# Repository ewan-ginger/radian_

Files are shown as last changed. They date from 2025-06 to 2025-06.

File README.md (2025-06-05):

# RADIAN_: An Open-Source IMU-Based Wireless Sensor Network for Team Sports Analytics

## Project Abstract

Access to performance analytics in team sports is increasingly essential at elite levels but remains largely inaccessible
to amateur players due to high system costs and complex workflows. Here we present RADIAN, an open-source,
IMU-based wireless sensor network embedded into lacrosse sticks, with the aim of enabling high-fidelity player and
team analytics without external infrastructure or specialist expertise. Built from off-the-shelf components, the system
uses the ESP-NOW protocol to transmit real-time inertial data up to 120m under ideal field conditions. We show
that the system achieves an F1 score of 0.95 in classifying six core lacrosse actions using a trained XGBoost model.
This was enabled by a novel, automated labelling pipeline developed for the sports context, reducing the need for
manual annotation and allowing scalable training data collection. Furthermore, an exploratory LLM reasoning layer
improved an ensemble model’s F1 score from 0.726 to 0.763 in game conditions, demonstrating potential for nuanced
event interpretation. RADIAN demonstrates that accurate, real-time analytics can be delivered through accessible
hardware, offering a pathway to close the gap between elite and grassroots athletic performance.

## Repository Structure
Use code with caution.

├── CAD/

│   ├── Master Node.f3z

│   ├── Master Node.step

│   ├── Slave Node.f3z

│   └── Slave Node.step

├── Code/                    

│   ├── Classification/       

│   ├── Firmware/             

│   ├── GUI/                  

│   └── LLM/                  

├── Data/                     

│   ├── 2v2 Data/             

│   └── Training Data/       

├── Personal Reflection/      

│   └── personal_reflection.md

├── Project Management/       

│   ├── gantt_chart.png

│   └── project_management.md

├── STLs/                     

│   ├── Butt End.stl

│   ├── Master Node Body Bottom.stl

│   ├── Master Node Top.stl

│   ├── Slave Node Body Left.stl

│   └── Slave Node Body Right.stl

├── Survey Results/         

│   ├── RADIAN Coach Feedback Survey(1-2...).xlsx

│   └── RADIAN Player Feedback Survey(1-1...).xlsx

├── Videos/                   

├── .gitignore              

├── README.md

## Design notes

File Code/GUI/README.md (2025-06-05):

# Radian - Sports Analytics Dashboard

This is a sports analytics dashboard built with Next.js, TypeScript, Shadcn UI, and Supabase. The application allows for real-time tracking and visualization of player movement data collected from ESP32 devices via the Web Serial API.

## Features

- Connect to ESP32 devices using Web Serial API
- Record and visualize player movement data in real-time
- Store and analyze historical session data
- Manage player profiles and session information
- Dark mode support with customizable theme

## Getting Started

First, run the development server:

```bash
npm run dev
# or
yarn dev
# or
pnpm dev
# or
bun dev
```

Open [http://localhost:3000](http://localhost:3000) with your browser to see the result.

## Project Structure

- `app/`: Next.js App Router pages and layouts
- `components/`: Reusable UI components
- `lib/`: Utility functions and services
  - `supabase/`: Supabase client and database operations
  - `serial/`: Web Serial API utilities
  - `data/`: Data processing and transformation
- `hooks/`: Custom React hooks
- `types/`: TypeScript type definitions
- `providers/`: Context providers for state management

## Technologies Used

- [Next.js](https://nextjs.org/) - React framework
- [TypeScript](https://www.typescriptlang.org/) - Type safety
- [Shadcn UI](https://ui.shadcn.com/) - Component library
- [Tailwind CSS](https://tailwindcss.com/) - Styling
- [Supabase](https://supabase.com/) - Backend and database
- [Web Serial API](https://developer.mozilla.org/en-US/docs/Web/API/Serial) - Device communication

## Development

This project follows a structured implementation plan with clearly defined steps. See the `project-steps.md` file for details on the implementation roadmap.

This project uses [`next/font`](https://nextjs.org/docs/app/building-your-application/optimizing/fonts) to automatically optimize and load [Geist](https://vercel.com/font), a new font family for Vercel.

## Learn More

To learn more about Next.js, take a look at the following resources:

- [Next.js Documentation](https://nextjs.org/docs) - learn about Next.js features and API.
- [Learn Next.js](https://nextjs.org/learn) - an interactive Next.js tutorial.

You can check out [the Next.js GitHub repository](https://github.com/vercel/next.js) - your feedback and contributions are welcome!

## Deploy on Vercel

The easiest way to deploy your Next.js app is to use the [Vercel Platform](https://vercel.com/new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) from the creators of Next.js.

Check out our [Next.js deployment documentation](https://nextjs.org/docs/app/building-your-application/deploying) for more details.

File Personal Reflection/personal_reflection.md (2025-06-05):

# Project Reflection

This project provided a rare opportunity to bring together a broad range of design engineering skills developed throughout my time at Imperial. From early-stage prototyping to machine learning and stakeholder engagement, the work demanded a multidisciplinary approach—and it was deeply rewarding to apply so many aspects of what I’ve learned in a single, cohesive output.

Revisiting the initial benchmarks—keeping the build under £50, under 55 grams, and achieving at least 92% F1 score on action recognition—offered a clear lens for evaluation. Reaching a build cost of around £30 and a final device weight of 25 grams felt like a genuine high point, especially when the 3D-printed housing slotted cleanly onto a standard lacrosse shaft, exactly as intended. That sense of translating a digital concept into a precise physical outcome echoed many of the rapid prototyping and CAD exercises I’d practised during my degree.

On the analytics side, achieving approximately 95% accuracy for isolated action detection was a strong validation of the machine-learning pipeline I developed. It drew directly on the technical foundations laid during data science and computing modules. However, the process also exposed areas for improvement—specifically, the automated labelling workflow introduced more “null” windows than expected, often due to actions occurring in close succession. In hindsight, I recognise that I moved too quickly from labelling to model training, and would now spend more time fine-tuning the segmentation thresholds. Balancing speed of development with rigour in validation is a key lesson I’ll take forward.

The technical range of the project meant constantly shifting gears. CAD and form development felt second nature; designing the butt-cap in Fusion 360 and iterating it rapidly was a familiar process. In contrast, firmware and embedded systems required learning on the fly. I had limited experience working at that level of hardware abstraction, so optimising the ESP32’s sleep modes and setting up hardware interrupts was a steep learning curve. Debugging power issues made me realise that app-level prototyping skills don’t always translate smoothly to embedded development—but the challenge was incredibly valuable.

On the machine learning front, building and training a Convolutional Neural Network pushed me to explore new tools like TensorFlow and experiment with techniques such as stratified cross-validation. Watching the model improve was satisfying, but I noticed a tendency to over-optimise—pursuing marginal gains without always asking whether the added complexity was meaningful. Going forward, I’ll set more disciplined performance thresholds and aim to simplify rather than overfit.

Beyond the technical work, the project gave me the chance to practise user research and product thinking in context. My training in user-centred design was particularly useful when gathering feedback from lacrosse players—turning those insights into tangible design improvements for the housing was a great example of design iteration grounded in real user needs. At the same time, trying to optimise the power budget exposed clear limitations in my understanding of electronics. Interpreting datasheets and modelling power draw didn’t come easily, and it’s an area I now plan to actively improve. I’m hoping to take on a smaller personal project—perhaps a basic wearable step counter—that will give me a focused way to learn about PCB design, battery selection, and current estimation without the overhead of a large codebase.

In many ways, this project felt like a culmination of my time at Imperial—it challenged me to integrate design, engineering, data, and human factors in a way that mirrored real-world product development. The variety of skills required made it especially enjoyable. To keep improving, I’ve already planned to refactor sections of the codebase into a more maintainable pipeline and conduct extended field tests—such as multi-stick scrimmages—to stress-test the system under more chaotic conditions. I’m also aiming to improve how I present results to non-technical stakeholders, using clearer visualisations and focusing on trade-offs rather than raw metrics.

Ultimately, RADIAN reminded me what I enjoy most about design engineering: the chance to solve meaningful problems by drawing on a wide and varied toolkit. It reinforced that successful products emerge not just from technical excellence, but from iterative thinking, user insight, and a willingness to keep learning across disciplines.

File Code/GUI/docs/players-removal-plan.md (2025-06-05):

# Players Table Removal Plan

This document outlines the steps taken to remove the unused `players` table and clarify the usage of `device_id` in the application.

## Summary of Changes

1. Dropped the `players` table from the database
2. Updated sensor data services to use `device_id` instead of `player_id`
3. Updated session services to work with the new data model
4. Added documentation about `device_id` not being a foreign key

## Database Changes

- Dropped the `players` table
- Kept `player_profiles` table which is still in use
- Changed references in `sensor_data` from `player_id` to `device_id`
- The `device_id` in `sensor_data` is a raw string identifier from the sensor device, not a foreign key

## Code Changes

### Files Deleted
- `radian-app/lib/services/player-service.ts` - Removed service for unused table

### Files Updated
- `radian-app/lib/services/sensor-data-service.ts`
  - Changed all functions to use `device_id` instead of `player_id`
  - Added documentation clarifying `device_id` is not a foreign key
  - Renamed functions to reflect the use of devices instead of players
  - Updated type assertions for safer property access

- `radian-app/lib/services/session-service.ts`
  - Removed references to the `PLAYERS_TABLE`
  - Updated `getSessionSummary` to use devices instead of players
  - Now links devices to players through `session_players` table

- `radian-app/types/database.types.ts`
  - Updated `SessionSummary` interface to use `devices` instead of `players`
  - Added `playerName` property to `SensorDataEntity` for convenience

## Device ID Clarification

The `device_id` in the `sensor_data` table:
1. Is a raw string identifier coming directly from the sensor device
2. Does not reference any other table as a foreign key
3. Is used to group sensor data by the physical device that generated it
4. Can be linked to a player through the `session_players` junction table

This approach provides better separation of concerns:
- Device information is kept separate from player profile information
- One player can use different devices across different sessions
- One device can be used by different players across different sessions
- Session data can be analyzed by device ID regardless of player assignment

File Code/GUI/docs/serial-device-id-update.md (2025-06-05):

# Serial Data Processing Update

This document outlines the changes needed to update the serial data processing to use `deviceID` instead of `playerID`.

## Background

The application receives sensor data over serial connections. Previously, this data contained a field identified as `playerID`. As part of our database restructuring, we have clarified that this is actually a device identifier and not directly linked to a player profile.

## Changes Required

1. In the serial packet parser (`radian-app/lib/serial/packet-parser.ts`), update all references from `playerID` to `deviceID`.

2. When processing the data packets, treat the identifier as a raw string from the device and not as a foreign key.

3. Update any processing code that looks up player information directly from the ID to instead use the `session_players` junction table.

## Implementation Details

### Packet Structure

The serial data packet structure should be updated in documentation and comments:

```
Data packet format:
- deviceID: String identifier for the physical sensor device
- timestamp: Milliseconds since epoch
- sensorData: Array of values for different sensors
  * accelerometer (x, y, z) in m/s²
  * gyroscope (x, y, z) in rad/s
  * magnetometer (x, y, z) in μT
  * orientation (x, y, z) as quaternion
  * battery_level (percentage)
```

### Data Processing

When receiving data from the serial port:

1. Extract the `deviceID` from the incoming packet
2. Use the `deviceID` to associate the data with the current session
3. Store the data in the `sensor_data` table with the `device_id` field set to this value
4. If player information is needed for display purposes, look it up using the `session_players` junction table

## Testing

After making these changes, test the serial communication to ensure:

1. Data is correctly received with the `deviceID` field
2. Data is properly stored in the database with the `device_id` field
3. Player association works correctly through the `session_players` table
4. Live data visualization correctly identifies and separates data by device

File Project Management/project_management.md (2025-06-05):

# Project Management

To effectively manage the RADIAN project's timeline and deliverables, a detailed project plan was initially developed and tracked using Microsoft Excel. This spreadsheet-based approach allowed for flexible input of tasks, start/end dates, durations, and dependencies, particularly useful during the iterative phases of hardware and software development. Key milestones, such as the Early and Late Stage Gateway reports, the pilot session with the England U20 Lacrosse team, and the final report submission, were clearly demarcated within this plan. For visual representation and inclusion in this report, the core task data and timeline information were then exported and used to generate the Gantt chart in this folder. This visual chart provides a clear overview of the project's phased execution, task scheduling, and critical path towards completion.

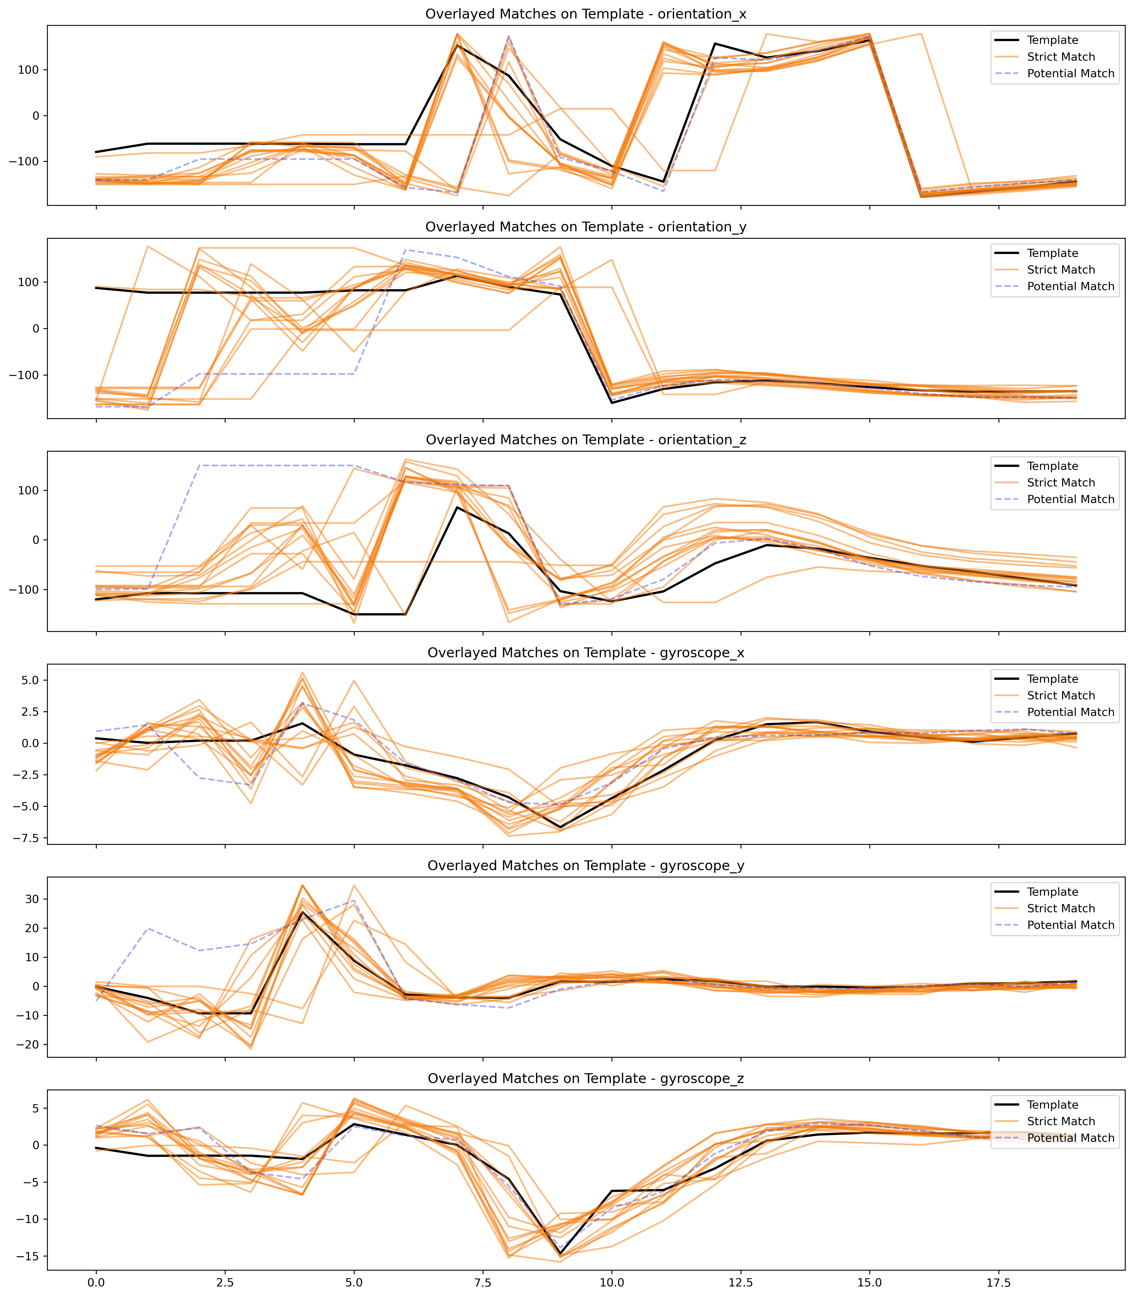
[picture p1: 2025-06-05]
Code/Classification/STUMPY/DTW_matches.png

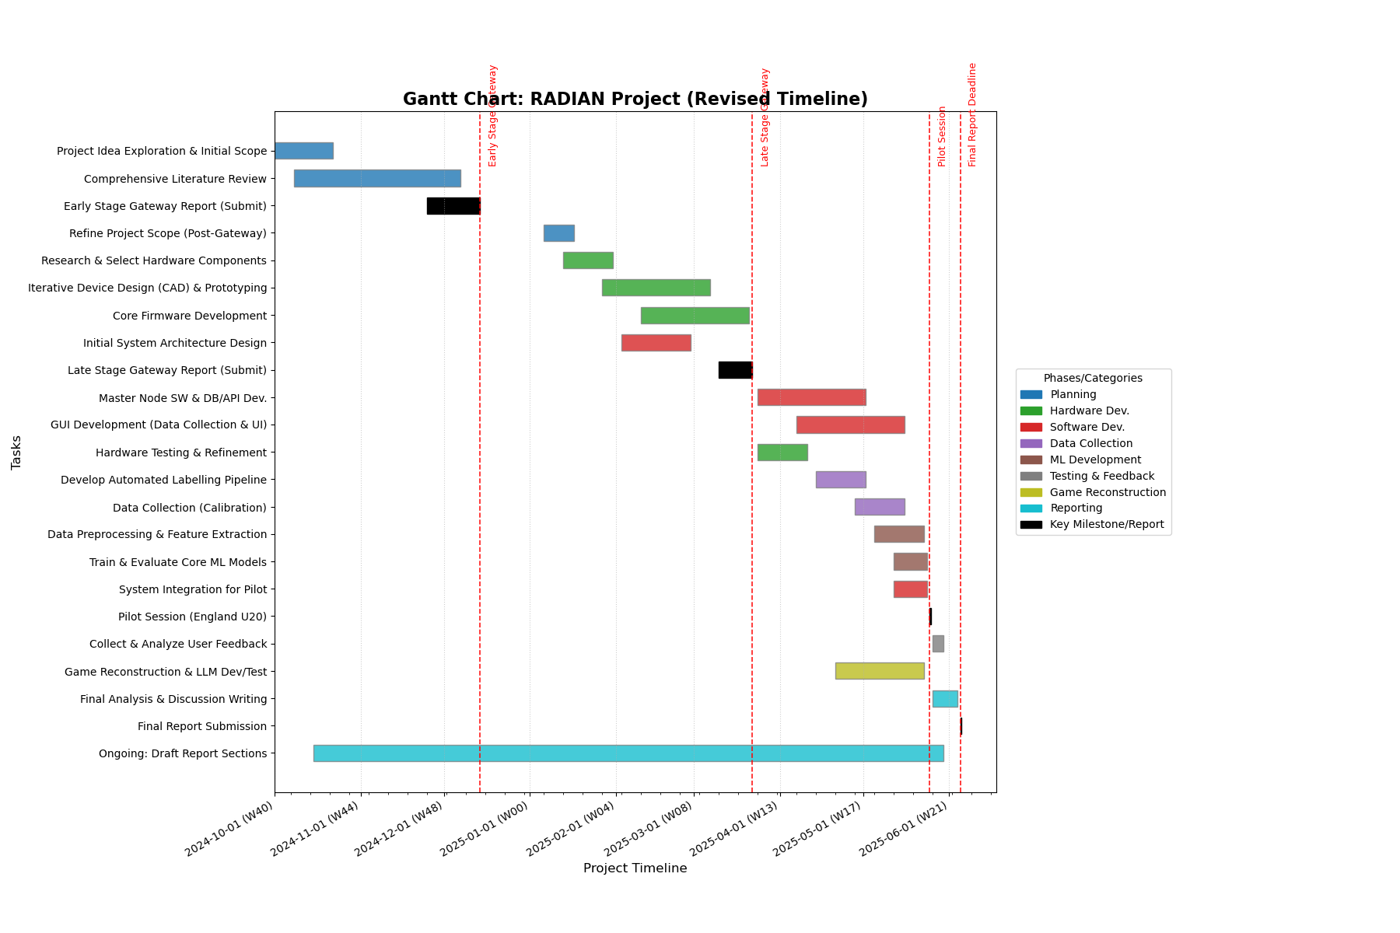
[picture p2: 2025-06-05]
Project Management/gantt_chart.png

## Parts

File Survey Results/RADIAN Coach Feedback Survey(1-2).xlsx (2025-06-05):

ID | Start time | Completion time | Email | Name | Last modified time | What is your name? | What is your position? | How easy would it be for other lacrosse teams to implement RADIAN? | How does RADIAN's cost compare to your budget expectations for analytics tools (£30 a device)? | Would you recommend RADIAN to coaches with limited technical resources? | How did players adapt to using the RADIAN system? | Did RADIAN interfere with your coaching or training methods? | How comfortable were players using RADIAN during competitive scenarios? | How reliable was RADIAN's data collection during your sessions? | How accurate did RADIAN's analytics appear compared to your observations? | How useful were RADIAN's insights for your coaching decisions? | Which analytics were most valuable for your coaching? | How did RADIAN data compare to video analysis in usefulness? | How likely would you be to recommend RADIAN to coaches in other sports? | Overall, how would you rate RADIAN as a coaching tool? | How likely are you to continue using RADIAN if it were available? | How does RADIAN compare to other sports technology you've used? | "How does RADIAN's cost-effectiveness and accessibility compare to other sports analytics solutions you've encountered? What impact could this have on lacrosse development at different levels, and... | "How does RADIAN compare to other sports technology or analysis methods you've used in your coaching career? What advantages do you see in RADIAN being open- source for the lacrosse coaching commu... | "In your professional opinion, what is RADIAN's most significant contribution to lacrosse coaching and player development? What are the main limitations you've observed, and what improvements woul...
1 | 2025-05-30 09:38 | 2025-05-30 09:46 | anonymous |  |  | Michael Armstrong | England Lacrosse Men's U20 Head Coach | Moderate – some teams might struggle | More affordable than expected | Recommend | Adapted immediately – no issues | No interference – seamless integration | Mostly comfortable – minor issues | Very good – minimal data loss | Mostly accurate – minor discrepancies | Very useful – enhanced existing methods | Goalie reaction time | About equal usefulness | Likely – good potential with modifications | Excellent – exceeded expectations | Definitely would continue using | Better than other systems | Has potential from performance metrics, through to development in terms of form and adds a different perspective to the sports analytics insight, not available in any other form of sports-science. | would adapt very well and fit in most sports - plus being easy to access and gain quick insights from it's very intuitive. the issue for example with GPS is you need someone to really own the insight and data, the RADIAN system whilst it has it's complexity is fairly easy and quick to get a meaningful output. | Additional insight not elsewhere available, for example auto collection of stats, plus reaction times and other qualitative data. Making the product easy to integrate to equipment, download, charge etc en-mass and then process the data into a dashboard would be the big next step.
2 | 2025-05-30 18:21 | 2025-05-30 18:29 | anonymous |  |  | Elliott Hurry | Coach | Moderate – some teams might struggle | Much more affordable than expected | Strongly recommend | Adapted immediately – no issues | Minimal interference – easy to work around | Very comfortable – no complaints | Excellent – consistent, complete data | Very accurate – perfectly matched observations | Extremely useful – changed coaching approach | Goalie reaction time | More useful than video | Very likely – excellent cross-sport potential | Excellent – exceeded expectations | Definitely would continue using | Much better than other systems | This could transform the landscape of lacrosse analytics and become an accessible tool for teams from international senior to grassroots junior level which is a massive step forward for the sport | Easier to implement and understand the applicability of RADIAN compared to other data analysis tools. RADIAN being open source could be a game changer for accessibility across the sport with it being amateur - it will enable all teams to access the level of data that national teams pay £1000’s to access. RADIAN has useful applications across any sport with some adaptations. | Coaching - real time data on activities such as face off and goalie reaction speed would have an immediate impact on coaches selection of players for crucial moments in game. Being able to observe the action of the lacrosse stick on screen has major positive implications in correction players technique in all aspects of the game (face off, passing, shooting) and providing real time statistics allows for insightful coaching moments across the field of play. Improvements - exploring the user interface further and creating actionable short cuts for non technically minded coaches would enable accessibility across the vast plethora of tech educated coaches.

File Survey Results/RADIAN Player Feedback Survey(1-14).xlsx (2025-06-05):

ID | Start time | Completion time | Email | Name | Last modified time | What is your name? | How would you rate the overall setup complexity of RADIAN as a system? | How much did the RADIAN device affect your movement during play? | How comfortable did you feel playing with the RADIAN device in stick? | Would you use the RADIAN system during competitive matches? | How often did you forget you were using the RADIAN system? | How reliable was the RADIAN system during your sessions? | Did you experience system failures or interruptions? | How accurate did the system's measurements seem based on your experience? | How useful were the analytics for understanding your performance? | Which analytics did you find most valuable? | How likely would you change your training based on RADIAN insights? | Overall, how would you rate your RADIAN experience? | How likely are you to recommend RADIAN to other lacrosse players? | If available today, would you want your team to use RADIAN? | Were the insights derived from the RADIAN data clear, easy to understand, and actionable for you?
1 | 2025-05-30 09:11 | 2025-05-30 09:12 | anonymous |  |  | James Mcilhagger | Very simple – anyone could use it | No effect – completely unnoticeable | Very comfortable throughout | Definitely yes | Almost always forgot about it | Excellent – no issues at all | 1–2 minor interruptions | Very accurate – matched my perception perfectly | Extremely useful – provided new insights | Box statistics (number of passes, shots, etc.) | Very likely – would definitely adjust | Excellent – exceeded expectations | Extremely likely (9–10/10) | Definitely yes | Mostly
2 | 2025-05-30 10:50 | 2025-05-30 10:52 | anonymous |  |  | Joachim Ruby | Moderate – some guidance needed | Minimal effect – barely noticed it | Very uncomfortable | Probably yes | Sometimes forgot about it | Very good – minimal problems | No failures | Somewhat accurate – some noticeable differences | Not very useful – limited insights | Goalie reaction time | Likely – would probably make changes | Very good – met expectations | Somewhat likely (5–6/10) | Probably yes | Sometimes
3 | 2025-05-30 11:29 | 2025-05-30 11:32 | anonymous |  |  | Nathan Leppinen | Very simple – anyone could use it | No effect – completely unnoticeable | Very comfortable throughout | Definitely yes | Often forgot about it | Good – occasional minor issues | 3–5 minor interruptions | Mostly accurate – minor differences | Somewhat useful – some helpful info | Faceoff relative reaction time | Likely – would probably make changes | Very good – met expectations | Very likely (7–8/10) | Definitely yes | Mostly
4 | 2025-05-30 11:26 | 2025-05-30 11:42 | anonymous |  |  | Jacob Andrew | Moderate – some guidance needed | Slight effect – occasionally aware of it | Mostly comfortable | Probably yes | Often forgot about it | Fair – some noticeable problems | 3–5 minor interruptions | Mostly accurate – minor differences | Somewhat useful – some helpful info | Box statistics (number of passes, shots, etc.) | Likely – would probably make changes | Good – satisfactory | Very likely (7–8/10) | Probably yes | Mostly
5 | 2025-05-30 12:19 | 2025-05-30 12:20 | anonymous |  |  | George smith | Moderate – some guidance needed | Minimal effect – barely noticed it | Very comfortable throughout | Maybe/unsure | Sometimes forgot about it | Very good – minimal problems | 1–2 minor interruptions | Mostly accurate – minor differences | Very useful – confirmed what I suspected | Faceoff relative reaction time | Likely – would probably make changes | Excellent – exceeded expectations | Very likely (7–8/10) | Probably yes | Mostly
6 | 2025-05-30 12:56 | 2025-05-30 12:58 | anonymous |  |  | Leo | Simple – minimal learning required | No effect – completely unnoticeable | Very comfortable throughout | Definitely yes | Often forgot about it | Excellent – no issues at all | No failures | Somewhat accurate – some noticeable differences | Very useful – confirmed what I suspected | Faceoff relative reaction time | Likely – would probably make changes | Excellent – exceeded expectations | Extremely likely (9–10/10) | Definitely yes | Mostly
7 | 2025-05-30 13:02 | 2025-05-30 13:04 | anonymous |  |  | Matty | Moderate – some guidance needed | No effect – completely unnoticeable | Very comfortable throughout | Definitely yes | Often forgot about it | Good – occasional minor issues | 1–2 minor interruptions | Somewhat accurate – some noticeable differences | Somewhat useful – some helpful info | Faceoff relative reaction time | Likely – would probably make changes | Excellent – exceeded expectations | Extremely likely (9–10/10) | Definitely yes | Mostly
8 | 2025-06-02 13:43 | 2025-06-02 13:45 | anonymous |  |  | San Ginger | Simple – minimal learning required | No effect – completely unnoticeable | Very comfortable throughout | Definitely yes | Often forgot about it | Excellent – no issues at all | 1–2 minor interruptions | Very accurate – matched my perception perfectly | Extremely useful – provided new insights | Box statistics (number of passes, shots, etc.) | Very likely – would definitely adjust | Excellent – exceeded expectations | Extremely likely (9–10/10) | Definitely yes | Mostly
9 | 2025-06-02 13:55 | 2025-06-02 13:57 | anonymous |  |  | Jeongheon Lee (Edward) | Simple – minimal learning required | No effect – completely unnoticeable | Very comfortable throughout | Definitely yes | Often forgot about it | Excellent – no issues at all | 1–2 minor interruptions | Very accurate – matched my perception perfectly | Extremely useful – provided new insights | Box statistics (number of passes, shots, etc.) | Very likely – would definitely adjust | Excellent – exceeded expectations | Extremely likely (9–10/10) | Definitely yes | Always
10 | 2025-06-02 13:57 | 2025-06-02 13:58 | anonymous |  |  | Aaron Edobor | Simple – minimal learning required | No effect – completely unnoticeable | Very comfortable throughout | Probably yes | Sometimes forgot about it | Very good – minimal problems | 1–2 minor interruptions | Mostly accurate – minor differences | Very useful – confirmed what I suspected | Shot speed | Likely – would probably make changes | Very good – met expectations | Extremely likely (9–10/10) | Definitely yes | Mostly
11 | 2025-06-02 14:04 | 2025-06-02 14:08 | anonymous |  |  | joe Gabriel | Moderate – some guidance needed | Minimal effect – barely noticed it | Very comfortable throughout | Probably yes | Often forgot about it | Poor – frequent issues | Several interruptions | Somewhat accurate – some noticeable differences | Not very useful – limited insights | Shot speed | Possibly – might consider adjustments | Very good – met expectations | Very likely (7–8/10) | Probably yes | Sometimes
12 | 2025-06-02 20:03 | 2025-06-02 20:05 | anonymous |  |  | Yoon Jin Kim | Simple – minimal learning required | No effect – completely unnoticeable | Very comfortable throughout | Definitely yes | Almost always forgot about it | Excellent – no issues at all | No failures | Very accurate – matched my perception perfectly | Extremely useful – provided new insights | Faceoff relative reaction time | Very likely – would definitely adjust | Excellent – exceeded expectations | Extremely likely (9–10/10) | Definitely yes | Always
13 | 2025-06-03 12:01 | 2025-06-03 12:03 | anonymous |  |  | George Jenkins | Very simple – anyone could use it | Minimal effect – barely noticed it | Very comfortable throughout | Definitely yes | Often forgot about it | Excellent – no issues at all | No failures | Mostly accurate – minor differences | Extremely useful – provided new insights | Goalie reaction time | Very likely – would definitely adjust | Excellent – exceeded expectations | Extremely likely (9–10/10) | Definitely yes | Always
14 | 2025-06-03 12:38 | 2025-06-03 12:39 | anonymous |  |  | Drew Wilkinson | Simple – minimal learning required | Minimal effect – barely noticed it | Very comfortable throughout | Probably yes | Almost always forgot about it | Very good – minimal problems | No failures | Mostly accurate – minor differences | Very useful – confirmed what I suspected | Pass speed | Possibly – might consider adjustments | Very good – met expectations | Extremely likely (9–10/10) | Definitely yes | Always

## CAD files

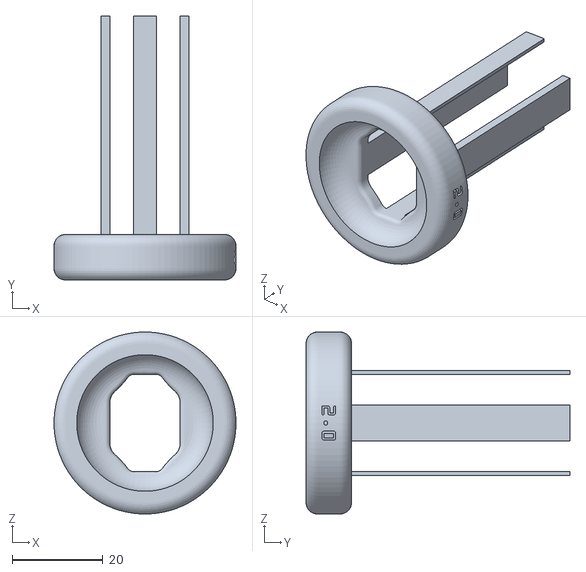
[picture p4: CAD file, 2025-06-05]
STLs/Butt End.stl
40.0 x 58.0 x 40.0

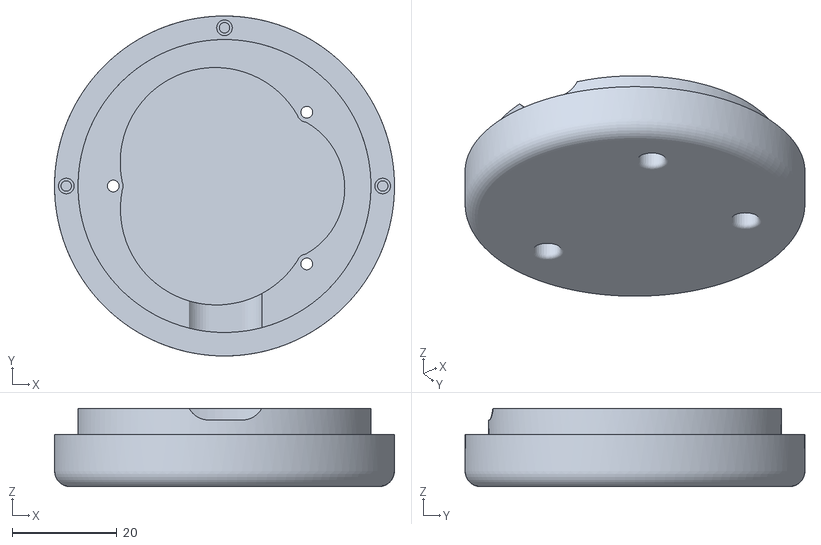
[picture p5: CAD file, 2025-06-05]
STLs/Master Node Body Bottom.stl
65.0 x 65.0 x 15.0

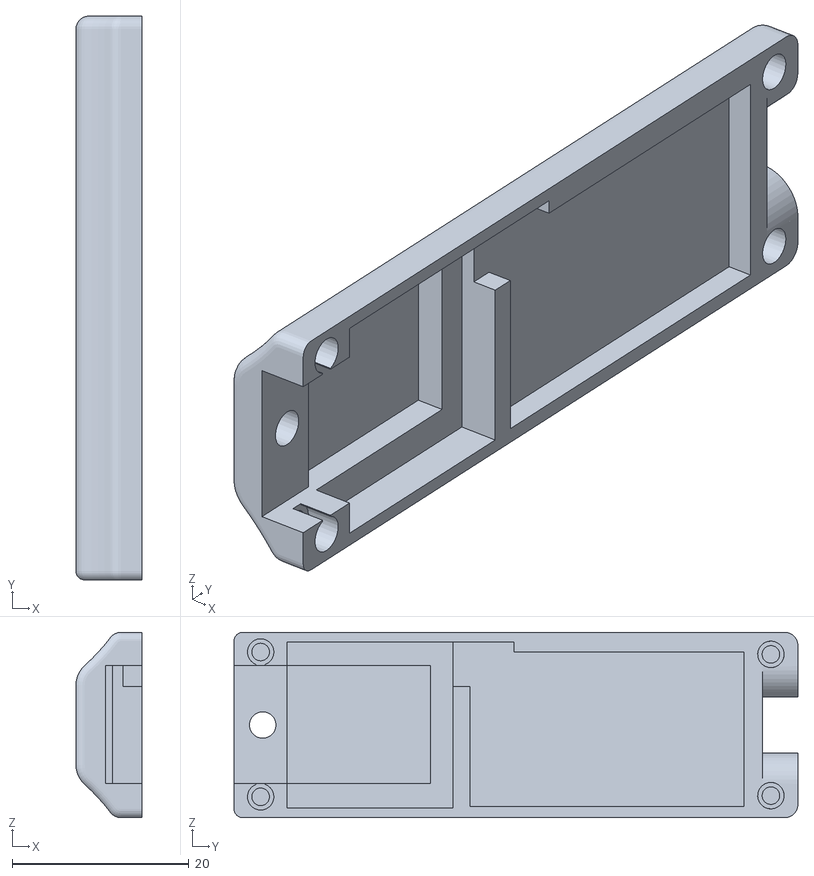
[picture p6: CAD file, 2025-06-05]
STLs/Slave Node Body Right.stl
7.50 x 63.9 x 21.0

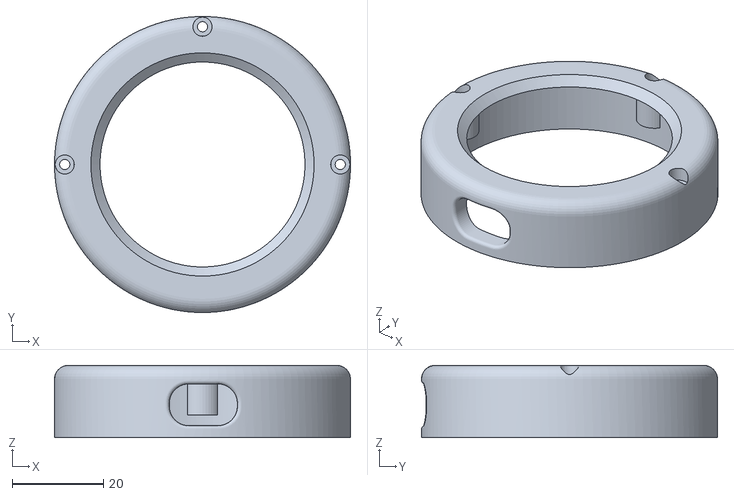
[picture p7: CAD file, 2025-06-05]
STLs/Master Node Top.stl
65.0 x 65.0 x 15.9

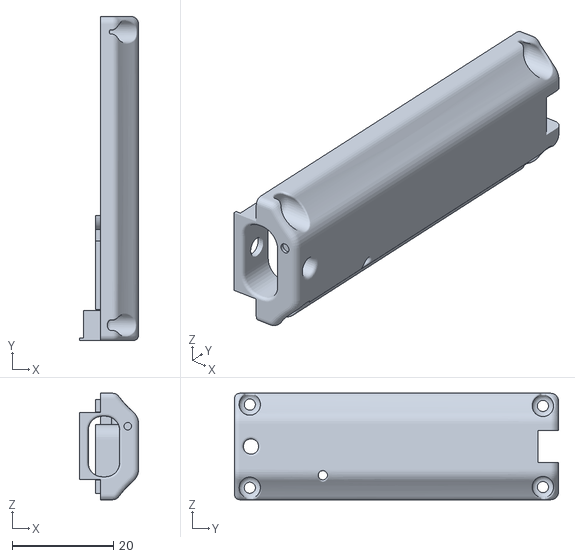
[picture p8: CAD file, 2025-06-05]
STLs/Slave Node Body Left.stl
11.7 x 63.9 x 21.0

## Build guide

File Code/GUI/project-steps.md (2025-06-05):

# Implementation Plan
## Project Setup and Configuration
- [x] Step 1: Initialize Next.js project with TypeScript
 - **Task**: Create a new Next.js project with TypeScript support, set up basic folder structure, and configure essential dependencies
 - **Files**:
   - `package.json`: Set up dependencies including next, react, react-dom, typescript
   - `tsconfig.json`: Configure TypeScript for Next.js
   - `.gitignore`: Standard Next.js gitignore file
   - `next.config.js`: Basic Next.js configuration
   - `README.md`: Project description and setup instructions
 - **Step Dependencies**: None
 - **User Instructions**: Run `npx create-next-app@latest radian --typescript` and follow the prompts to set up the project

- [x] Step 2: Install and configure Shadcn UI with dark mode
 - **Task**: Set up Shadcn UI, configure dark mode theme, and establish the design system with specified accent colors
 - **Files**:
   - `package.json`: Add Shadcn UI dependencies
   - `components.json`: Shadcn UI configuration
   - `tailwind.config.js`: Configure color scheme with green, blue, and red accents
   - `app/globals.css`: Set up global CSS including dark mode
   - `providers/theme-provider.tsx`: Set up theme provider component
   - `lib/utils.ts`: Utility functions for styling and theme management
 - **Step Dependencies**: Step 1
 - **User Instructions**: Follow the Shadcn UI installation instructions with `npx shadcn-ui@latest init` and add base components with `npx shadcn-ui@latest add button card toast`

- [x] Step 3: Set up Supabase integration
 - **Task**: Configure Supabase client for Next.js, set up environment variables, and create utility functions for database operations
 - **Files**:
   - `package.json`: Add Supabase dependencies
   - `.env.local.example`: Template for environment variables
   - `lib/supabase/client.ts`: Client-side Supabase configuration
   - `lib/supabase/server.ts`: Server-side Supabase configuration
   - `types/supabase.ts`: TypeScript types for Supabase data
 - **Step Dependencies**: Step 1
 - **User Instructions**: 
   1. Create a Supabase project at supabase.com
   2. Rename `.env.example` to `.env.local` so it has the following variables:
      ```
      NEXT_PUBLIC_SUPABASE_URL=your_supabase_url
      NEXT_PUBLIC_SUPABASE_ANON_KEY=your_supabase_anon_key
      ```

## Database Schema and Data Management
- [x] Step 4: Create database schema for players and session data
 - **Task**: Design and implement database tables to store player information, session data, and sensor readings
 - **Files**:
   - `lib/supabase/schema.ts`: Database schema definitions
   - `types/database.types.ts`: TypeScript types for database entities
   - `scripts/seed-database.ts`: Script to initialize database with minimal seed data
 - **Step Dependencies**: Step 3
 - **User Instructions**: Run the following SQL in the Supabase SQL Editor:
   ```sql
   -- Create players table
   CREATE TABLE players (
     id UUID PRIMARY KEY DEFAULT uuid_generate_v4(),
     name TEXT NOT NULL,
     device_id TEXT,
     created_at TIMESTAMP WITH TIME ZONE DEFAULT NOW()
   );

   -- Create sessions table
   CREATE TABLE sessions (
     id UUID PRIMARY KEY DEFAULT uuid_generate_v4(),
     name TEXT,
     start_time TIMESTAMP WITH TIME ZONE DEFAULT NOW(),
     end_time TIMESTAMP WITH TIME ZONE,
     created_at TIMESTAMP WITH TIME ZONE DEFAULT NOW()
   );

   -- Create sensor_data table
   CREATE TABLE sensor_data (
     id UUID PRIMARY KEY DEFAULT uuid_generate_v4(),
     session_id UUID REFERENCES sessions(id),
     player_id UUID REFERENCES players(id),
     timestamp BIGINT NOT NULL,
     accelerometer_x REAL,
     accelerometer_y REAL,
     accelerometer_z REAL,
     gyroscope_x REAL,
     gyroscope_y REAL,
     gyroscope_z REAL,
     magnetometer_x REAL,
     magnetometer_y REAL,
     magnetometer_z REAL,
     orientation_x REAL,
     orientation_y REAL,
     orientation_z REAL,
     battery_level REAL,
     created_at TIMESTAMP WITH TIME ZONE DEFAULT NOW()
   );

   -- Insert default player
   INSERT INTO players (name, device_id) VALUES ('Player 1', '1');
   ```

- [x] Step 5: Implement data service functions
 - **Task**: Create service functions to handle data operations (create, read, update) for players, sessions, and sensor data
 - **Files**:
   - `lib/services/player-service.ts`: Functions for player data management
   - `lib/services/session-service.ts`: Functions for session data management
   - `lib/services/sensor-data-service.ts`: Functions for sensor data operations
 - **Step Dependencies**: Step 4
 - **User Instructions**: None

## Web Serial API Integration
- [x] Step 6: Implement Web Serial API utilities
 - **Task**: Create utility functions to connect to ESP32 devices using Web Serial API, handle connection status, and manage serial communication
 - **Files**:
   - `lib/serial/serial-connection.ts`: Core Web Serial API functionality
   - `lib/serial/serial-protocol.ts`: Protocol definitions for communicating with ESP32 devices
   - `hooks/useSerialConnection.ts`: React hook for managing serial connections
   - `types/serial.ts`: TypeScript types for serial communication
 - **Step Dependencies**: Step 1
 - **User Instructions**: None

- [x] Step 7: Implement data packet processing
 - **Task**: Create functions to parse and process 15-value data packets from ESP32 devices, normalize timestamps, and prepare data for visualization
 - **Files**:
   - `lib/serial/packet-parser.ts`: Functions to parse binary data packets
   - `lib/data/data-processor.ts`: Process and transform data for storage and visualization
   - `lib/data/data-normalizer.ts`: Normalize timestamp data
   - `types/data-packet.ts`: TypeScript types for data packets
 - **Step Dependencies**: Step 6
 - **User Instructions**: None

## UI Components
- [x] Step 8: Create core layout and navigation components
 - **Task**: Implement the main layout structure with dark mode theme integration and responsive design
 - **Files**:
   - `app/layout.tsx`: Root layout with theme provider
   - `app/page.tsx`: Main page container
   - `components/layout/Header.tsx`: Application header
   - `components/layout/Footer.tsx`: Application footer
   - `components/ui/ThemeToggle.tsx`: Toggle for dark/light mode
 - **Step Dependencies**: Step 2
 - **User Instructions**: None

- [x] Step 9: Implement device connection interface
 - **Task**: Create UI components for connecting to ESP32 devices, showing connection status, and controlling data recording
 - **Files**:
   - `components/devices/DeviceConnection.tsx`: Main device connection component
   - `components/devices/ConnectionStatus.tsx`: Status indicator component
   - `components/devices/DeviceIllustration.tsx`: Visual representation of the device
   - `components/devices/ControlButtons.tsx`: Start/stop recording buttons
   - `components/ui/StatusPill.tsx`: Reusable status indicator pill component
 - **Step Dependencies**: Steps 6, 8
 - **User Instructions**: None

- [x] Step 10: Implement data visualization components
 - **Task**: Create components for visualizing player orientation data with auto-scrolling graphs
 - **Files**:
   - `package.json`: Add data visualization dependencies (recharts)
   - `components/data/OrientationGraph.tsx`: Graph component for orientation data
   - `components/data/DataDisplay.tsx`: Container for data visualization
   - `components/data/DataControls.tsx`: Controls for data display
   - `hooks/useDataVisualization.ts`: Hook for managing visualization state
 - **Step Dependencies**: Step 8
 - **User Instructions**: Install recharts with `npm install recharts`

- [ ] Step 11: Create player information components
 - **Task**: Implement components for displaying and editing player information
 - **Files**:
   - `components/players/PlayerCard.tsx`: Card component for player data
   - `components/players/PlayerNameEditor.tsx`: Inline editor for player name
   - `components/players/PlayerStatistics.tsx`: Component for displaying player stats
   - `hooks/usePlayerData.ts`: Hook for managing player data
 - **Step Dependencies**: Steps 5, 8
 - **User Instructions**: None

## Main Application Features
- [x] Step 12: Implement hardware connection feature
 - **Task**: Integrate the Web Serial API utilities with the UI to create a complete hardware connection feature
 - **Files**:
   - `app/page.tsx`: Update main page to include device connection section
   - `components/devices/DeviceSection.tsx`: Container for all device-related components
   - `hooks/useDeviceConnection.ts`: Comprehensive hook for device connection management
   - `context/DeviceContext.tsx`: Context for sharing device connection state
 - **Step Dependencies**: Steps 6, 9
 - **User Instructions**: None

- [x] Step 13: Implement data recording and processing
 - **Task**: Create functionality to start/stop recording sessions, process incoming data, and store it in Supabase
 - **Files**:
   - `hooks/useDataRecording.ts`: Hook for managing data recording state
   - `lib/data/session-manager.ts`: Functions for creating and managing recording sessions
   - `lib/data/data-storage.ts`: Functions for storing processed data in Supabase
   - `context/RecordingContext.tsx`: Context for sharing recording state
 - **Step Dependencies**: Steps 5, 7, 12
 - **User Instructions**: None

- [ ] Step 14: Implement player data visualization feature
 - **Task**: Integrate data processing with visualization components to display live player data
 - **Files**:
   - `components/players/PlayerDataBox.tsx`: Main container for player data visualization
   - `hooks/usePlayerVisualization.ts`: Hook for managing player visualization state
   - `lib/data/visualization-data-transformer.ts`: Transform data for visualization
   - `context/VisualizationContext.tsx`: Context for sharing visualization state
 - **Step Dependencies**: Steps 10, 11, 13
 - **User Instructions**: None

- [ ] Step 15: Implement data history and playback
 - **Task**: Create functionality to retrieve historical data from Supabase and play it back in the visualization components
 - **Files**:
   - `components/history/SessionList.tsx`: Component to list recorded sessions
   - `components/history/SessionPlayer.tsx`: Component to play back recorded sessions
   - `lib/data/history-loader.ts`: Functions to load historical data
   - `hooks/useSessionPlayback.ts`: Hook for managing session playback
 - **Step Dependencies**: Steps 5, 14
 - **User Instructions**: None

## Finalization and Optimization
- [ ] Step 16: Implement error handling and notifications
 - **Task**: Add comprehensive error handling throughout the application and implement a notification system for user feedback
 - **Files**:
   - `components/ui/Toast.tsx`: Toast notification component
   - `components/ui/ErrorDisplay.tsx`: Error display component
   - `context/NotificationContext.tsx`: Context for managing notifications
   - `lib/error-handler.ts`: Centralized error handling utilities
   - `hooks/useErrorHandling.ts`: Hook for error handling in components
 - **Step Dependencies**: Step 8
 - **User Instructions**: None

- [ ] Step 17: Add responsive design and polish UI
 - **Task**: Ensure the application is fully responsive and add final UI polish for a professional look and feel
 - **Files**:
   - `app/globals.css`: Update global styles for responsiveness
   - `components/layout/ResponsiveContainer.tsx`: Container with responsive behavior
   - `components/ui/ResponsiveGrid.tsx`: Grid layout that adapts to screen size
   - Update various component files to enhance mobile responsiveness
 - **Step Dependencies**: Steps 9, 10, 11, 14
 - **User Instructions**: None

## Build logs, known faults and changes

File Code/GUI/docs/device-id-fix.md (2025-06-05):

# Device ID Fix for Session Data Saving

## Issue Summary
The web app was unable to save session data after the database schema changes that replaced `player_id` with `device_id` in the `sensor_data` table.

## Root Cause
The issue was in the serial data processing pipeline. The packet parser wasn't correctly extracting the device ID from the data packet. The device ID is actually the first value in the packet (index 0).

## Changes Made

1. **Updated packet format documentation**:
   - Clarified that the first value (index 0) in the packet is the device ID
   - Updated the indices for all other values to reflect the correct positions

2. **Fixed the parseSensorData function**:
   - Modified to extract the device ID from the first position in the data array
   - Properly shifted the indices for all other values (timestamp, accelerometer, etc.)
   - Converted the device ID to a string as required by the database

3. **Added debugging logs**:
   - Enhanced `insertSensorData` and `insertSensorDataBatch` functions with additional logging
   - Improved error messages to include the data that failed to insert

## Packet Format
The correct packet format from the ESP32 device is:
```
[0]: device ID (unique identifier for the sensor device)
[1]: timestamp (ms since device boot)
[2-4]: accelerometer (x, y, z) in m/s²
[5-7]: gyroscope (x, y, z) in rad/s
[8-10]: magnetometer (x, y, z) in μT
[11-13]: orientation (x, y, z) in degrees
[14]: battery level (percentage)
```

## Testing
To verify this fix:

1. Connect a sensor device to the app
2. Start a new recording session
3. Ensure data is being saved to the database
4. Check the browser console for logs showing the device ID
5. Check the Supabase console to confirm data is being inserted with the correct device ID

## Future Improvements
In the future, we should implement a more robust way to handle device IDs:

1. Modify the firmware to include the device ID in the packet data
2. Update the packet parser to extract the device ID from the packet
3. Alternatively, assign device IDs dynamically based on the serial port or connection

## Related Files
- `radian-app/lib/serial/serial-protocol.ts`
- `radian-app/lib/serial/packet-parser.ts`
- `radian-app/lib/services/sensor-data-service.ts`

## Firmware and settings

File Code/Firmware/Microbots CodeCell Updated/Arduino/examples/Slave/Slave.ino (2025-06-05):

#include <esp_now.h>
#include <WiFi.h>
#include <CodeCell.h>

CodeCell myCodeCell;

// --- Your existing global variables and structs ---
float deviceID = 1.0;
// ... (other sensor data floats) ...
float timeStamp = 0.0;
float battery = 0.0;
float orientX = 0.0; float orientY = 0.0; float orientZ = 0.0;
float accelX = 0.0; float accelY = 0.0; float accelZ = 0.0;
float gyroX = 0.0; float gyroY = 0.0; float gyroZ = 0.0;
float magX = 0.0; float magY = 0.0; float magZ = 0.0;


typedef struct SensorData {
    float deviceID;
    float timeStamp;
    float battery;
    float orientX, orientY, orientZ;
    float accelX, accelY, accelZ;
    float gyroX, gyroY, gyroZ;
    float magX, magY, magZ;
} SensorData;

typedef struct Message {
    char command[10];
} Message;

SensorData sensorData;
Message receivedMsg;

// --- State Flags ---
volatile bool device_is_connected = false;
volatile bool sensing = false;

// --- Timestamp for Idle Timeout ---
unsigned long last_activity_timestamp = 0;

// MAC Address of the ESP-NOW master device
uint8_t masterAddress[6] = {0xd8, 0x3b, 0xda, 0xa0, 0x75, 0x04}; // IMPORTANT: Replace with your master's MAC Address

// --- Configuration for Deep Sleep and Listening ---
#define CHARGING_DEEP_SLEEP_DURATION_S 60
#define DEEP_SLEEP_DURATION_S 5
#define LISTEN_CONNECT_DURATION_MS 5000
#define IDLE_TIMEOUT_BEFORE_START_MS (60 * 1000UL) // 60 seconds

// ESP-NOW Callback function when data is received
void OnDataRecv(const esp_now_recv_info_t *info, const uint8_t *incomingData, int len) {
    if (len >= sizeof(receivedMsg.command) -1 && len < sizeof(receivedMsg.command)) {
        memcpy(receivedMsg.command, incomingData, len);
        receivedMsg.command[len] = '\0';
    } else if (len == sizeof(receivedMsg.command)) {
         memcpy(receivedMsg.command, incomingData, sizeof(receivedMsg.command));
         // Assuming sender ensures null termination if command fills buffer
    } else {
        Serial.printf("Received data of unexpected length: %d bytes. Max command length is %d.\n", len, sizeof(receivedMsg.command)-1);
        return;
    }

    Serial.printf("Received command: '%s'\n", receivedMsg.command);

    if (strcmp(receivedMsg.command, "connect") == 0) {
        device_is_connected = true;
        sensing = false;
        last_activity_timestamp = millis();
        Serial.println("Device CONNECTED by ESP-NOW command. Awaiting 'start' command (60s timeout).");
    } else if (strcmp(receivedMsg.command, "start") == 0) {
        if (device_is_connected) {
            sensing = true;
            Serial.println("Sensing STARTED by ESP-NOW command.");
        } else {
            Serial.println("'start' command received but device not connected. Please send 'connect' first.");
        }
    } else if (strcmp(receivedMsg.command, "stop") == 0) {
        sensing = false;
        device_is_connected = false;
        Serial.println("Sensing STOPPED and device DISCONNECTED by ESP-NOW command. Will check for 'connect' or sleep.");
    } else {
        Serial.printf("Unknown command received: %s\n", receivedMsg.command);
    }
}

// Function to send sensor data
void sendSensorData() {
    sensorData.deviceID = deviceID;
    sensorData.timeStamp = millis();
    sensorData.battery = myCodeCell.BatteryLevelRead();

    myCodeCell.Motion_RotationRead(orientX, orientY, orientZ);
    sensorData.orientX = orientX; sensorData.orientY = orientY; sensorData.orientZ = orientZ;

    myCodeCell.Motion_LinearAccRead(accelX, accelY, accelZ);
    sensorData.accelX = accelX; sensorData.accelY = accelY; sensorData.accelZ = accelZ;

    myCodeCell.Motion_GyroRead(gyroX, gyroY, gyroZ);
    sensorData.gyroX = gyroX; sensorData.gyroY = gyroY; sensorData.gyroZ = gyroZ;

    myCodeCell.Motion_MagnetometerRead(magX, magY, magZ);
    sensorData.magX = magX; sensorData.magY = magY; sensorData.magZ = magZ;

    esp_err_t result = esp_now_send(masterAddress, (uint8_t *)&sensorData, sizeof(sensorData));
    // Reduce serial spam during active sensing
    // if (result != ESP_OK) { Serial.print("Error sending sensor data: "); Serial.println(esp_err_to_name(result)); }
}

// Initialize ESP-NOW
void initEspNow() {
    WiFi.mode(WIFI_STA);
    if (esp_now_init() != ESP_OK) {
        Serial.println("Error initializing ESP-NOW");
        return;
    }
    Serial.println("ESP-NOW Initialized.");
    esp_now_register_recv_cb(OnDataRecv);
    esp_now_peer_info_t peerInfo = {};
    memcpy(peerInfo.peer_addr, masterAddress, 6);
    peerInfo.channel = 0;
    peerInfo.encrypt = false;
    if (esp_now_add_peer(&peerInfo) != ESP_OK) {
        Serial.println("Failed to add ESP-NOW peer");
    } else {
        Serial.println("ESP-NOW Peer Added.");
    }
}

// Prepare for and enter deep sleep
void enterDeepSleep() {
    // This function performs the actions needed just before sleeping
    Serial.printf("Preparing to enter deep sleep for %u seconds...\n", DEEP_SLEEP_DURATION_S);
    esp_now_deinit();
    WiFi.disconnect(true);
    WiFi.mode(WIFI_OFF);
    myCodeCell.Sleep(DEEP_SLEEP_DURATION_S); // Call the library's sleep function
    // Execution halts here until wake-up
}

void setup() {
    Serial.begin(115200);
    delay(1000);
    Serial.println("\n----------------------");
    Serial.println("Device Waking Up / Booting...");

    myCodeCell.Init(MOTION_ROTATION + MOTION_LINEAR_ACC + MOTION_GYRO + MOTION_MAGNETOMETER);
    Serial.println("CodeCell Initialized.");

    if (myCodeCell.WakeUpCheck()) {
        Serial.println("Woke up from deep sleep (timer).");
    } else {
        Serial.println("Woke up from Power-On / Reset.");
    }

    device_is_connected = false;
    sensing = false;
    last_activity_timestamp = 0;

    initEspNow();
    Serial.println("Setup complete. Defaulting to 'Awaiting Connect' state.");
}

void loop() {
    if (!device_is_connected) {
        // --- STATE: AWAITING 'connect' COMMAND (or sleeping / USB idle) ---

        // Call Run() periodically even when not connected to keep power status updated
        // Using a low frequency like 10Hz is sufficient here.
        myCodeCell.Run(10); // <-- ADD THIS LINE HERE

        // The rest of your existing code for this block follows...

        Serial.printf("Device not connected. Listening for 'connect' command for %d ms...\n", LISTEN_CONNECT_DURATION_MS);
        unsigned long listenStartTime = millis();
        bool connect_command_received = false;

        while (millis() - listenStartTime < LISTEN_CONNECT_DURATION_MS) {
            // You could also call Run() inside this while loop if needed,
            // but calling it just before the loop and after might be enough.
            myCodeCell.Run(10); // <-- ADD THIS LINE HERE
            if (device_is_connected) {
                connect_command_received = true;
                break;
            }
            delay(20);
        }

        if (connect_command_received) {
             // Connect command was received, device_is_connected is now true.
             // Loop will iterate, and the 'else' block below will be entered.
        } else {
             // Listen window for 'connect' ended, still not connected.
             // Check power state before deciding whether to sleep or stay awake (if USB powered).

             Serial.println("Waiting briefly before reading power state...");
             delay(100); // *** ADD A DELAY HERE (e.g., 100ms) ***

             // Call Run() again just before reading the status to ensure it's as current as possible
             myCodeCell.Run(10); // <-- ADD THIS LINE HERE AGAIN (optional, but safer)

             int power_state = myCodeCell.PowerStateRead();
             Serial.printf("Power state check: %d (0=Lipo, 1=USB, 2=Init, 3=Low, 4=Charged, 5=Charging)\n", power_state);

             // ... (rest of your power state check and sleep logic)
            if (power_state == 0) {
                Serial.println("Listen window ended. No 'connect'. Running on Battery. Going to sleep.");
                enterDeepSleep();
            } else {
                Serial.println("Listen window ended. No 'connect'. USB/Charging/Low/Init state detected. Staying awake and listening for 'connect' again.");
                delay(1000);
                myCodeCell.Run(10);
            }
        }
    } else {
        // --- STATE: CONNECTED and OPERATIONAL ---
        // ... (Your existing code for the connected state, including myCodeCell.Run(50))
        if (!sensing) {;
            if (millis() - last_activity_timestamp > IDLE_TIMEOUT_BEFORE_START_MS) {
                Serial.println("Idle timeout: No 'start' command received within 60s after 'connect'. Disconnecting.");
                device_is_connected = false; // Fall back to the !device_is_connected block next loop
            }
        }

        if (device_is_connected) {
            if (myCodeCell.Run(51)) { // <-- This call is already here and correct for sensing
                if (sensing) {
                    sendSensorData();
                }
            }
        }
    }
}

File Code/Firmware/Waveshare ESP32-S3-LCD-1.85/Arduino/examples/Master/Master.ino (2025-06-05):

#include "Display_ST77916.h"
#include "LVGL_Driver.h"
#include <esp_now.h>
#include <WiFi.h>

// Define the number of slave devices
#define NUM_SLAVES 5

/*
master mac address: d8:3b:da:a0:75:04
slave 1 mac address: 98:3d:ae:3b:46:0c
slave 2 mac address: 98:3d:ae:31:3d:30
slave 3 mac address: 98:3d:ae:38:dd:70
slave 4 mac address: 98:3d:ae:39:10:50
slave 5 mac address: 98:3d:ae:37:db:b4
*/

// Array of slave MAC addresses
uint8_t slaveAddresses[NUM_SLAVES][6] = {
    {0x98, 0x3d, 0xae, 0x3b, 0x46, 0x0c},
    {0x98, 0x3d, 0xae, 0x31, 0x3d, 0x30},
    {0x98, 0x3d, 0xae, 0x38, 0xdd, 0x70},
    {0x98, 0x3d, 0xae, 0x39, 0x10, 0x50},
    {0x98, 0x3d, 0xae, 0x37, 0xdb, 0xb4}
};

// Struct to keep track of each slave's data and status
typedef struct {
    bool connected;
    unsigned long lastReceived;
    int packetCount;
} SlaveInfo;

SlaveInfo slaveInfoArray[NUM_SLAVES];

typedef struct SensorData {
    float deviceID;
    float timeStamp;
    float battery;

    float orientX;
    float orientY;
    float orientZ;

    float accelX;
    float accelY;
    float accelZ;

    float gyroX;
    float gyroY;
    float gyroZ;

    float magX;
    float magY;
    float magZ;
} SensorData;

typedef struct Message {
    char command[10];
} Message;

// Array to store data from each slave
SensorData receivedDataArray[NUM_SLAVES];
Message msg;

volatile int totalPacketCount = 0;
unsigned long lastTime = 0;

// Function to find the slave index based on MAC address
int findSlaveIndex(const uint8_t *mac_addr) {
    for (int i = 0; i < NUM_SLAVES; i++) {
        bool match = true;
        for (int j = 0; j < 6; j++) {
            if (mac_addr[j] != slaveAddresses[i][j]) {
                match = false;
                break;
            }
        }
        if (match) return i;
    }
    return -1; // Not found
}

void IRAM_ATTR OnDataRecv(const esp_now_recv_info_t *info, const uint8_t *incomingData, int len) {
    // Find which slave sent the data
    int slaveIndex = findSlaveIndex(info->src_addr);
    
    if (slaveIndex != -1) {
        memcpy(&receivedDataArray[slaveIndex], incomingData, sizeof(SensorData));
        
        // Update slave info
        slaveInfoArray[slaveIndex].lastReceived = millis();
        slaveInfoArray[slaveIndex].packetCount++;
        totalPacketCount++;
        
        // Print received data with device identifier
        SensorData data = receivedDataArray[slaveIndex];
        Serial.printf("DATA: %.2f,%.2f,%.2f,%.2f,%.2f,%.2f,%.2f,%.2f,%.2f,%.2f,%.2f,%.2f,%.2f,%.2f,%.2f\n", 
            data.deviceID, data.timeStamp, data.battery, 
            data.orientX, data.orientY, data.orientZ, 
            data.accelX, data.accelY, data.accelZ, 
            data.gyroX, data.gyroY, data.gyroZ, 
            data.magX, data.magY, data.magZ);
    } else {
        Serial.println("Data received from unknown device");
    }
}

void sendCommandToAll(const char *command) {
    strcpy(msg.command, command);
    for (int i = 0; i < NUM_SLAVES; i++) {
        if (slaveInfoArray[i].connected) {
            esp_err_t result = esp_now_send(slaveAddresses[i], (uint8_t *)&msg, sizeof(msg));
            Serial.printf("Command sent to Slave %d: %s\n", i + 1, 
                          result == ESP_OK ? "Success" : "Failed");
        }
    }
}

void sendCommandToSlave(int slaveIndex, const char *command) {
    if (slaveIndex >= 0 && slaveIndex < NUM_SLAVES && slaveInfoArray[slaveIndex].connected) {
        strcpy(msg.command, command);
        esp_err_t result = esp_now_send(slaveAddresses[slaveIndex], (uint8_t *)&msg, sizeof(msg));
        Serial.printf("Command sent to Slave %d: %s\n", slaveIndex + 1, 
                      result == ESP_OK ? "Success" : "Failed");
    } else {
        Serial.printf("Invalid slave index or slave not connected: %d\n", slaveIndex + 1);
    }
}

// Callback when data is sent
void OnDataSent(const uint8_t *mac_addr, esp_now_send_status_t status) {
    int slaveIndex = findSlaveIndex(mac_addr);
    if (slaveIndex != -1) {
        Serial.printf("Delivery to Slave %d %s\n", slaveIndex + 1,
                     status == ESP_NOW_SEND_SUCCESS ? "succeeded" : "failed");
    }
}

void showConnectedScreen() {
    lv_obj_clean(lv_scr_act());
    lv_obj_t *scr = lv_scr_act();
    lv_obj_set_style_bg_color(scr, lv_color_black(), 0);

    lv_obj_t *circle = lv_obj_create(scr);
    lv_obj_set_size(circle, 300, 300);
    lv_obj_align(circle, LV_ALIGN_CENTER, 0, 0);
    lv_obj_set_style_radius(circle, LV_RADIUS_CIRCLE, 0);
    lv_obj_set_style_border_color(circle, lv_palette_main(LV_PALETTE_GREEN), 0);
    lv_obj_set_style_border_width(circle, 5, 0);
    lv_obj_set_style_bg_opa(circle, LV_OPA_TRANSP, 0);

    lv_obj_t *label = lv_label_create(scr);
    lv_label_set_text(label, "Connected");
    lv_obj_set_style_text_color(label, lv_palette_main(LV_PALETTE_GREEN), 0);
    lv_obj_set_style_text_font(label, &lv_font_montserrat_28, 0);
    lv_obj_align(label, LV_ALIGN_CENTER, 0, 0);
}

void setup() {
    Serial.begin(115200);
    WiFi.mode(WIFI_STA);
    
    if (esp_now_init() != ESP_OK) {
        Serial.println("ESP-NOW Init Failed");
        return;
    }
    
    esp_now_register_recv_cb(OnDataRecv);
    esp_now_register_send_cb(OnDataSent);
    
    // Initialize slave info array
    for (int i = 0; i < NUM_SLAVES; i++) {
        slaveInfoArray[i].connected = false;
        slaveInfoArray[i].lastReceived = 0;
        slaveInfoArray[i].packetCount = 0;
        
        // Register each slave as a peer
        esp_now_peer_info_t peerInfo = {};
        memcpy(peerInfo.peer_addr, slaveAddresses[i], 6);
        peerInfo.channel = 0;
        peerInfo.encrypt = false;
        
        if (esp_now_add_peer(&peerInfo) == ESP_OK) {
            slaveInfoArray[i].connected = true;
            Serial.printf("Successfully added Slave %d as peer\n", i + 1);
        } else {
            Serial.printf("Failed to add Slave %d as peer\n", i + 1);
        }
    }

    Backlight_Init();
    LCD_Init();
    Lvgl_Init();
    showConnectedScreen();
}
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

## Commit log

2025-06-05 init survey
    [RADIAN Coach Feedback Survey(1-2).xlsx, RADIAN Player Feedback Survey(1-14).xlsx]
2025-06-05 init STLs
    [Butt End.stl, Master Node Body Bottom.stl, Master Node Top.stl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]
2025-06-05 init data
    [2v2_1.csv, 2v2_5.csv, pass_template_1.csv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]
2025-06-05 init CAD
